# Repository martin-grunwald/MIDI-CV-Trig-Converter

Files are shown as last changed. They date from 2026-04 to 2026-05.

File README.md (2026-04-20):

# MIDI-CV-Trig-Converter

# Zadání
Navrhněte a realizujte převodník rozhraní MIDI na řídicí signály analogových syntezátorů CV/Trig pro modulární systém Eurorack. Převodník bude umožňovat převod zpráv nota zapnuta/vypnuta, zpráv Pitch bend change a zpráv pro změnu kontroleru. Převodník bude disponovat polyfonními výstupy CV, Gate a Trig pro výšku tónu a stlačení klávesy a dalšími výstupy řídicího signálu CV pro kontrolery a bude umožňovat výběr MIDI kontrolru pro každý z těchto výstupů. Převodník bude také obsahovat výstupy Trig pro převod zpráv synchronizace MIDI Clock.

Diagram bez názvu

# Popis
Z MIDI inputu půjdou data do UART portu na STM32 (31250 baud). Zapíše se Note On, Note Off, Výška tónu, Pitch bend a Clock. Note On, Note Off a výšky tónu se uloží pro každý hlas zvlášť.
Polyfonie se může řídit jako round robin nebo last note priority.

Switchem se dají přepínat režimy:
1. 4 hlasy polyfonie a žádný výstup CV z MIDI CC
2. Monofonie a 3 výstupy CV z MIDI CC

Režimů bude nakonec možná víc, ale pak už by se všechno mělo řešit v softwaru. Akorát by se pak použil vícepólový přepínač.

MIDI clock běží na 24ppqn, takže v STM32 bude potřeba vydělit clock rate (na čtvrťovou nebo osminovou notu, podle toho, jak bude potřeba).

Z MCU modelů nejvhodněji vypadá STM32F405RG + 2 externí 12-bitové, dvoukanálové převodníky (MCP4922).

Rozsah CV a V/Oct bude 0 - 10 V, přičemž pitch bend se bude přičítat k výstupu, takže to se bude řídit softwarově.
Jestli bude na výstupu převodníku 0,33V (nebo 0,5V), tak se dá potom použít ještě buffer (OPA1612) a pokud by bylo potřeba, tak ještě jednoduchý RC filtr na vyhlazení průběhu napětí a ochranné diody.

Gate signály by mohly jít z GPIO a do MOSFETu 2N7002. MOSFETY by měly umožnit odebírat růyné namětí v závislosti na tom, jaké napětí je konkrétně potřeba na trigger/gate inputu na jiném modulu (většinou 5V/10V/12V).

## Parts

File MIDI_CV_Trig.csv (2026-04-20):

Reference | Qty | Value | DNP | Exclude from BOM | Exclude from Board | Footprint | Datasheet
C1,C2,C3,C4,C5 | 5 | 100n |  |  |  | Capacitor_SMD:C_0805_2012Metric | ~
C6,C8 | 2 | 10u |  |  |  | Capacitor_SMD:C_0805_2012Metric | ~
C7,C9,C10,C15,C16,C19,C21,C22,C23,C24,C25,C26,C27,C28,C29,C30,C31,C34 | 18 | 0.1u |  |  |  | Capacitor_SMD:C_0805_2012Metric | ~
C11,C12 | 2 | 22u |  |  |  | Capacitor_SMD:C_0805_2012Metric | ~
C13 | 1 | 75p |  |  |  | Capacitor_SMD:C_0805_2012Metric | ~
C14 | 1 | 10u |  |  |  | Capacitor_THT:CP_Radial_D5.0mm_P2.00mm | ~
C17 | 1 | 22u |  |  |  | Capacitor_THT:CP_Radial_D5.0mm_P2.00mm | ~
C18,C20 | 2 | 47ux16V |  |  |  | Capacitor_THT:CP_Radial_D5.0mm_P2.00mm | ~
C32,C33 | 2 | 2.2u |  |  |  | Capacitor_SMD:C_0805_2012Metric | ~
C35 | 1 | 1u |  |  |  | Capacitor_SMD:C_0805_2012Metric | ~
D1 | 1 | 1N4148 |  |  |  | Diode_THT:D_DO-35_SOD27_P7.62mm_Horizontal | https://assets.nexperia.com/documents/data-sheet/1N4148_1N4448.pdf
D2,D3 | 2 | SS34 |  |  |  | Diode_SMD:D_SMA | https://www.vishay.com/docs/88751/ss32.pdf
F1,F2 | 2 | Fuse_Small |  |  |  | Fuse:Fuse_1206_3216Metric | ~
FB1,FB2,FB3,FB4 | 4 | FerriteBead_Small |  |  |  | Inductor_SMD:L_1206_3216Metric | ~
J1 | 1 | Conn_02x05_Odd_Even |  |  |  | Connector_IDC:IDC-Header_2x05_P2.54mm_Vertical | ~
J2,J13 | 2 | Conn_01x03_Pin |  |  |  | Connector_PinHeader_2.54mm:PinHeader_1x03_P2.54mm_Vertical | ~
J3 | 1 | CV1_OUT |  |  |  | Connector_Audio:Jack_3.5mm_QingPu_WQP-PJ398SM_Vertical_CircularHoles | ~
J4 | 1 | CV2_OUT |  |  |  | Connector_Audio:Jack_3.5mm_QingPu_WQP-PJ398SM_Vertical_CircularHoles | ~
J5 | 1 | CV3_OUT |  |  |  | Connector_Audio:Jack_3.5mm_QingPu_WQP-PJ398SM_Vertical_CircularHoles | ~
J6 | 1 | CV4_OUT |  |  |  | Connector_Audio:Jack_3.5mm_QingPu_WQP-PJ398SM_Vertical_CircularHoles | ~
J7 | 1 | CLOCK_OUT |  |  |  | Connector_Audio:Jack_3.5mm_QingPu_WQP-PJ398SM_Vertical_CircularHoles | ~
J8 | 1 | GATE1_OUT |  |  |  | Connector_Audio:Jack_3.5mm_QingPu_WQP-PJ398SM_Vertical_CircularHoles | ~
J9 | 1 | GATE2_OUT |  |  |  | Connector_Audio:Jack_3.5mm_QingPu_WQP-PJ398SM_Vertical_CircularHoles | ~
J10 | 1 | GATE3_OUT |  |  |  | Connector_Audio:Jack_3.5mm_QingPu_WQP-PJ398SM_Vertical_CircularHoles | ~
J11 | 1 | GATE4_OUT |  |  |  | Connector_Audio:Jack_3.5mm_QingPu_WQP-PJ398SM_Vertical_CircularHoles | ~
J12 | 1 | Conn_ARM_JTAG_SWD_10 |  |  |  | Connector_PinHeader_1.27mm:PinHeader_2x05_P1.27mm_Vertical | http://infocenter.arm.com/help/topic/com.arm.doc.ddi0314h/DDI0314H_coresight_components_trm.pdf
L1 | 1 | 10u |  |  |  | Inductor_SMD:L_6.3x6.3_H3 | ~
Q1,Q2,Q3,Q4,Q5 | 5 | 2N7002 |  |  |  | Package_TO_SOT_SMD:SOT-23 | https://www.onsemi.com/pub/Collateral/NDS7002A-D.PDF
R1 | 1 | 49R9 |  |  |  | Resistor_SMD:R_0805_2012Metric | ~
R2,R25,R27,R30,R33,R36 | 6 | 100k |  |  |  | Resistor_SMD:R_0805_2012Metric | ~
R3 | 1 | 13.3k |  |  |  | Resistor_SMD:R_0805_2012Metric | ~
R4 | 1 | 220 |  |  |  | Resistor_SMD:R_0805_2012Metric | ~
R5,R9,R10,R11,R12,R17,R18,R19,R20,R24,R28,R31,R34,R37,R38,R39,R40 | 17 | 10k |  |  |  | Resistor_SMD:R_0805_2012Metric | ~
R6,R13,R14,R21,R22 | 5 | 1k |  |  |  | Resistor_SMD:R_0805_2012Metric | ~
R7,R8,R15,R16,R23,R26,R29,R32,R35 | 9 | 100R |  |  |  | Resistor_SMD:R_0805_2012Metric | ~
TP1 | 1 | TEST_-12V |  |  |  | TestPoint:TestPoint_Pad_1.5x1.5mm | ~
TP2 | 1 | TEST_+12V |  |  |  | TestPoint:TestPoint_Pad_1.5x1.5mm | ~
TP3 | 1 | TEST_5V |  |  |  | TestPoint:TestPoint_Pad_1.5x1.5mm | ~
TP4 | 1 | TEST_3V3 |  |  |  | TestPoint:TestPoint_Pad_1.5x1.5mm | ~
TP5 | 1 | TEST_GND |  |  |  | TestPoint:TestPoint_Pad_2.5x2.5mm | ~
TP6 | 1 | TEST_NRST |  |  |  | TestPoint:TestPoint_Pad_1.5x1.5mm | ~
TP7 | 1 | TEST_DAC1_RAW |  |  |  | TestPoint:TestPoint_Pad_1.5x1.5mm | ~
TP8 | 1 | TEST_DAC2_RAW |  |  |  | TestPoint:TestPoint_Pad_1.5x1.5mm | ~
TP9 | 1 | TEST_DAC3_RAW |  |  |  | TestPoint:TestPoint_Pad_1.5x1.5mm | ~
TP10 | 1 | TEST_DAC4_RAW |  |  |  | TestPoint:TestPoint_Pad_1.5x1.5mm | ~
TP11 | 1 | TEST_DAC1_OUT |  |  |  | TestPoint:TestPoint_Pad_1.5x1.5mm | ~
TP12 | 1 | TEST_DAC2_OUT |  |  |  | TestPoint:TestPoint_Pad_1.5x1.5mm | ~
TP13,TP14 | 2 | TEST_DAC3_OUT |  |  |  | TestPoint:TestPoint_Pad_1.5x1.5mm | ~
U1 | 1 | STM32F405RGTx |  |  |  | Package_QFP:LQFP-64_10x10mm_P0.5mm | https://www.st.com/resource/en/datasheet/stm32f405rg.pdf
U2 | 1 | TPS54302 |  |  |  | Package_TO_SOT_SMD:SOT-23-6 | http://www.ti.com/lit/ds/symlink/tps54302.pdf
U3,U9 | 2 | OPA2277 |  |  |  | Package_SO:SOIC-8_3.9x4.9mm_P1.27mm | https://www.ti.com/lit/ds/symlink/opa2277.pdf
U4 | 1 | LD1117V33 |  |  |  | Package_TO_SOT_SMD:SOT-23_Handsoldering | https://www.st.com/resource/en/datasheet/ld1117.pdf
U5 | 1 | 6N137 |  |  |  | Package_DIP:DIP-8_W7.62mm | https://docs.broadcom.com/docs/AV02-0940EN
U6,U8 | 2 | MCP4822 |  |  |  | Package_SO:SOIC-8_3.9x4.9mm_P1.27mm | http://ww1.microchip.com/downloads/en/DeviceDoc/20002249B.pdf
U7,U10 | 2 | OPA1612AxD |  |  |  | Package_SO:SOIC-8_3.9x4.9mm_P1.27mm | http://www.ti.com/lit/ds/symlink/opa1612.pdf

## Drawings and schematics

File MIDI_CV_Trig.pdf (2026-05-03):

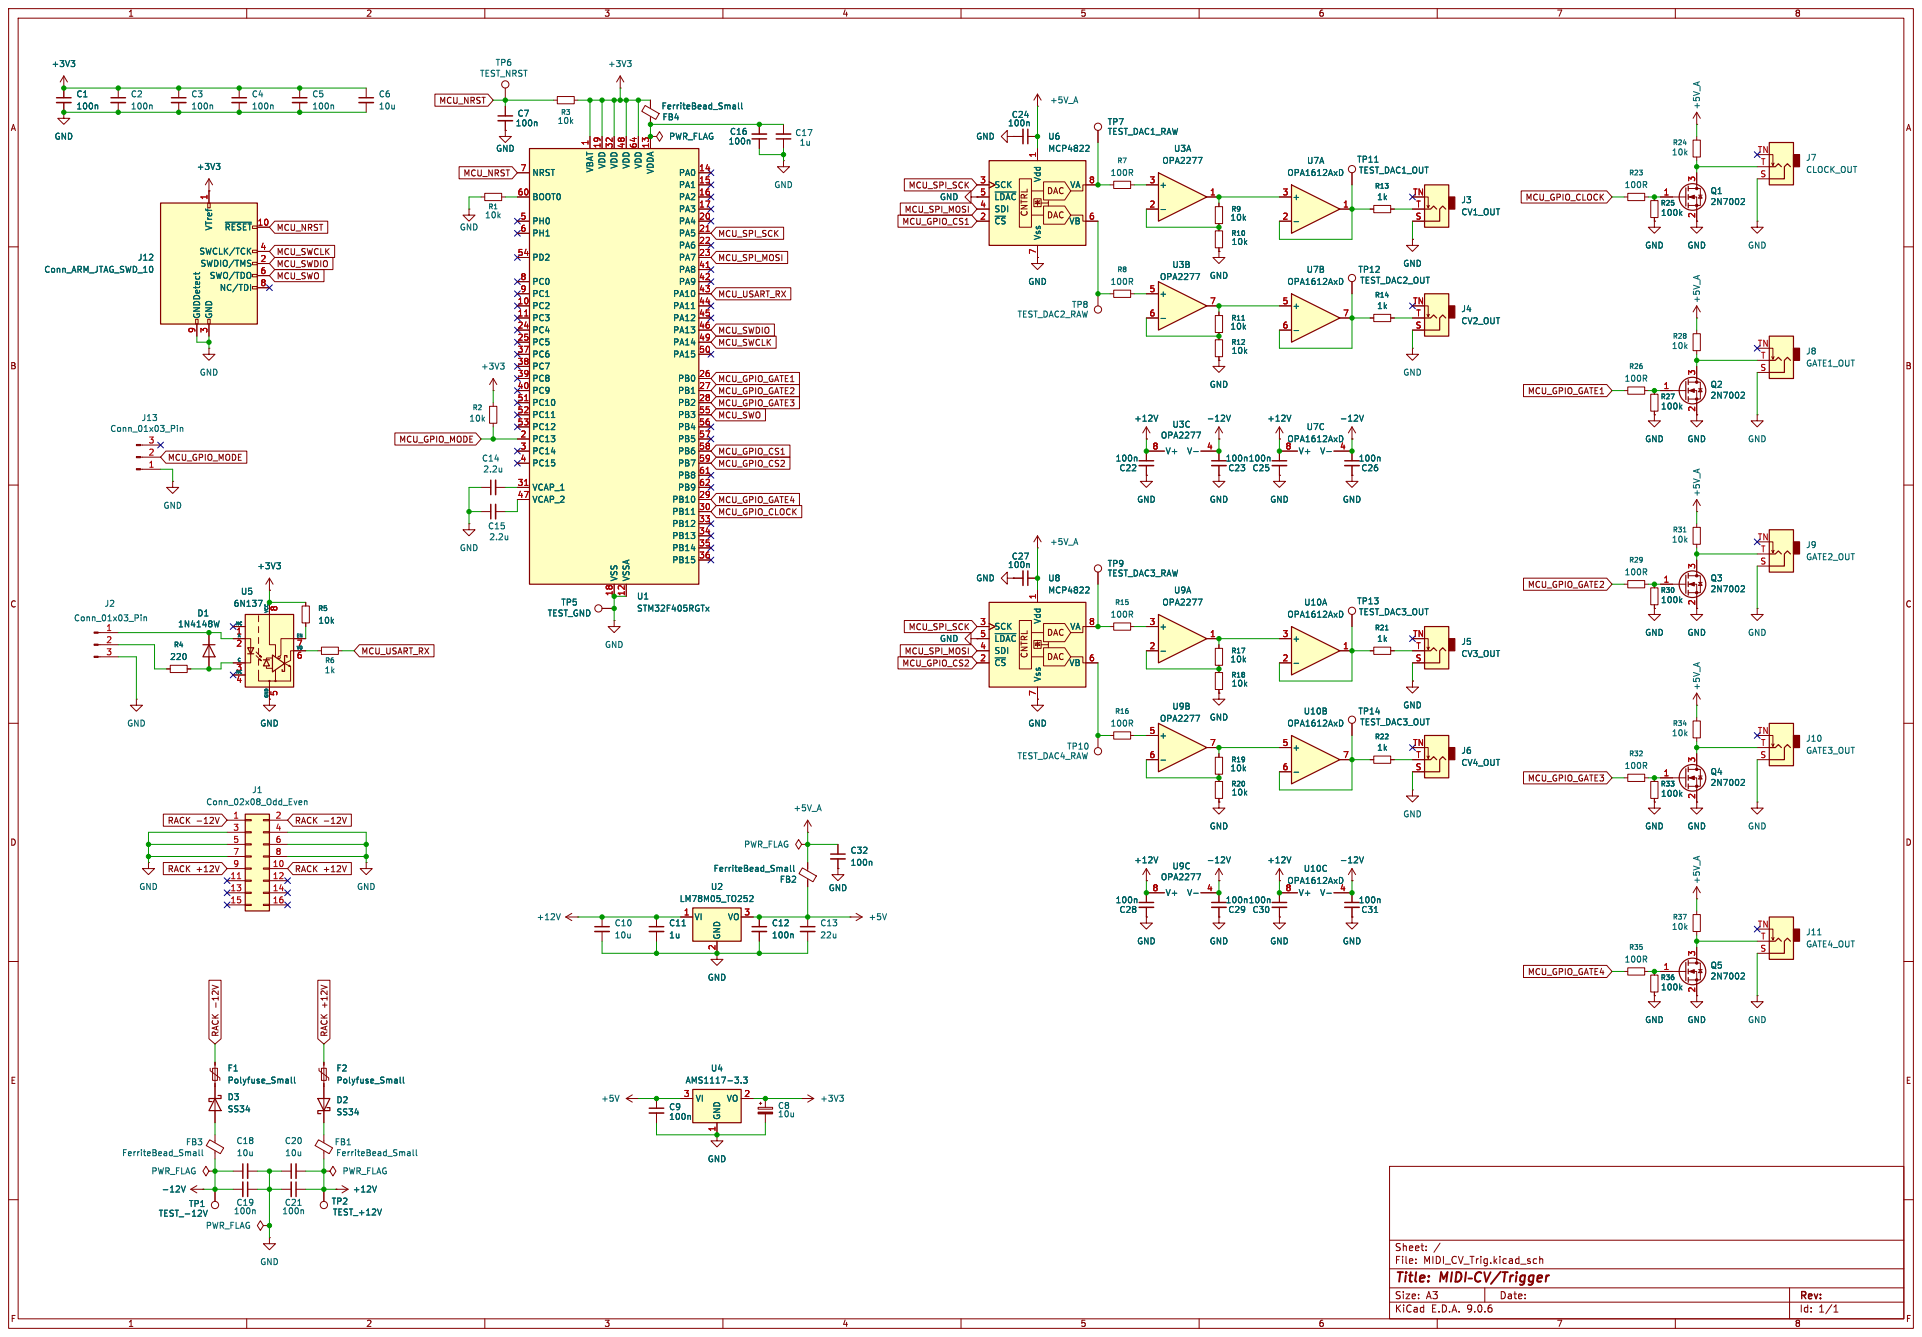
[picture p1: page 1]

3 ~{RESET}10 SWCLK/TCK 4 SWDIO/TMS 2 SWO/TDO 6 NC/TDI 8 C1
100n GND

1 VDD 19 VDD 32 VSS 18 VDD 48 VSSA 12 VDD 64 VDDA 13 PA0 14 PA1 15 PA2 16 PA3 17 PA4 20 PA5 21 PA6 22 PA7 23 PA8 41 PA9 42 PA10 43 PA11 44 PA12 45 PA13 46 PA14 49 PA15 50 PB0 26 PB1 27 PB2 28 PB3 55 PB4 56 PB5 57 PB6 58 PB7 59 PB8 61 PB9 62 PB10 29 PB11 30 PB12 33 PB13 34 PB14 35 PB15 36 +3V3 U5

1 VDD 19 VDD 32 VSS 18 VDD 48 VSSA 12 VDD 64 VDDA 13 PA0 14 PA1 15 PA2 16 PA3 17 PA4 20 PA5 21 PA6 22 PA7 23 PA8 41 PA9 42 PA10 43 PA11 44 PA12 45 PA13 46 PA14 49 PA15 50 PB0 26 PB1 27 PB2 28 PB3 55 PB4 56 PB5 57 PB6 58 PB7 59 PB8 61 PB9 62 PB10 29 PB11 30 PB12 33 PB13 34 PB14 35 PB15 36 U1STM32F405RGTx R14 1k TP12 TEST_DAC2_OUT C14
J3CV1_OUT GND

1 Vss 7 VA 8 VB 6 GND GND

3 ~{RESET}10 SWCLK/TCK 4 SWDIO/TMS 2 SWO/TDO 6 NC/TDI 8

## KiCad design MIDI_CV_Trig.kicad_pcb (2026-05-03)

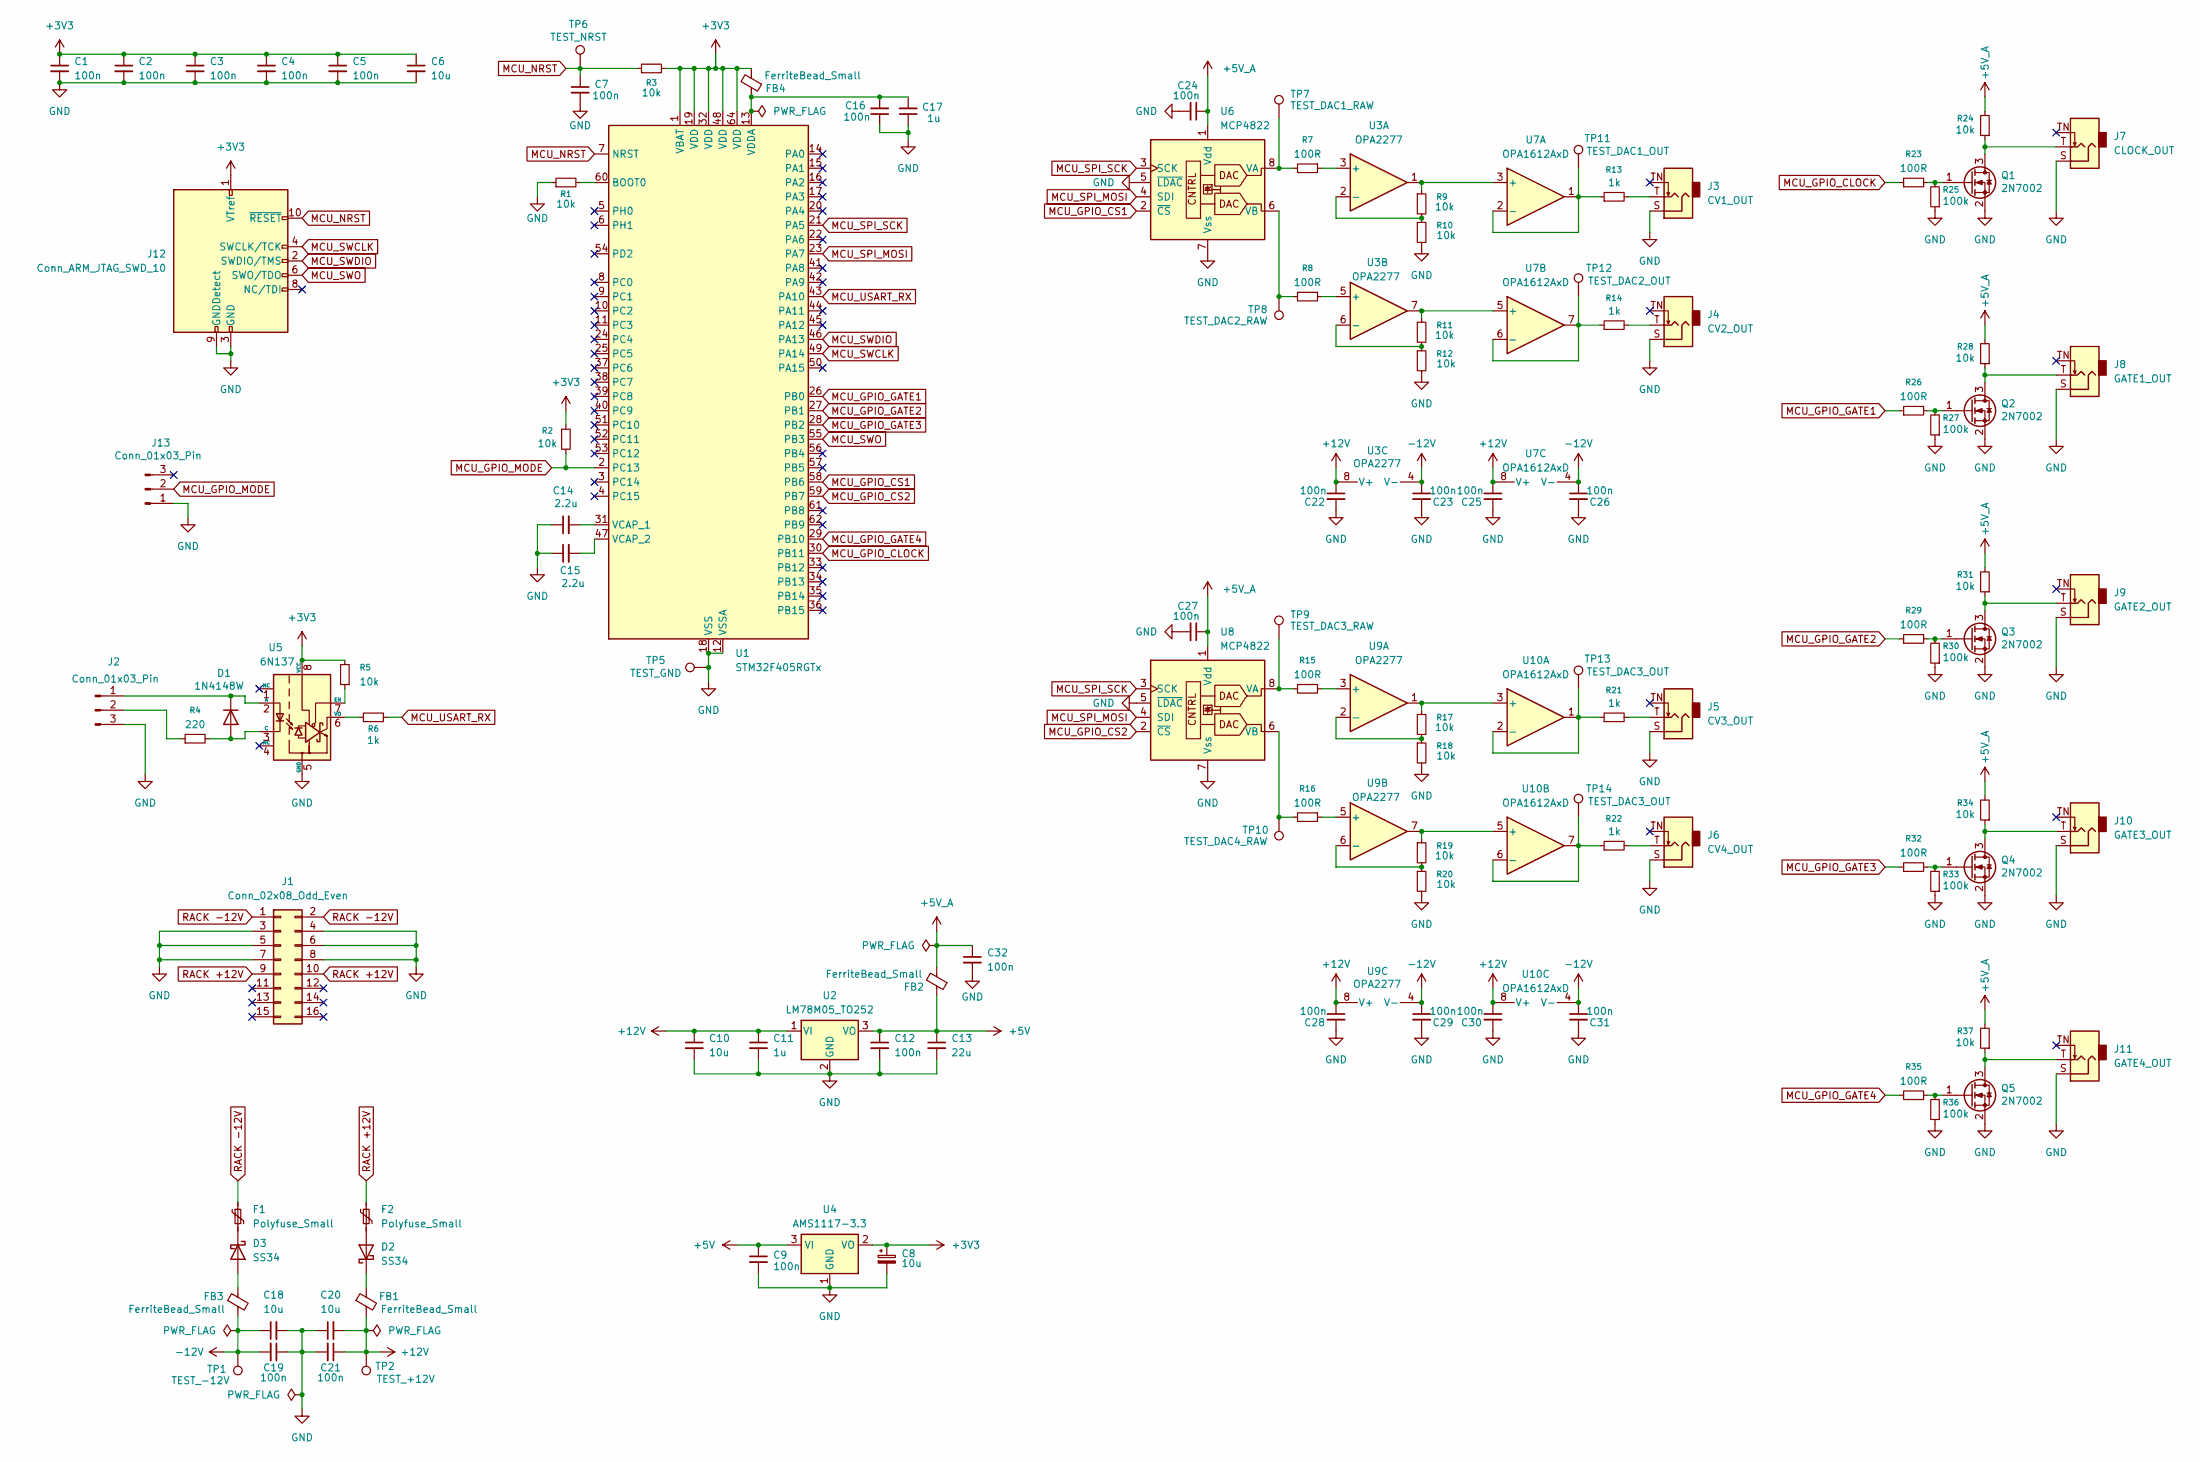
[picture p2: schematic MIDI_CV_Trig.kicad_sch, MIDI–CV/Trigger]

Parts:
C1, C2, C3, C4, C5, C7, C9, C12, C16, C22, C23, C24, C25, C26, C27, C28, C29, C30, C31, C32: 100n; C_0603_1608Metric; JLCPCB C14663
C6, C10, C18, C20: 10u; C_1206_3216Metric; JLCPCB C13585
C8: 10u; CP_EIA-3216-18_Kemet-A; JLCPCB C7171
C11, C17: 1u; C_0603_1608Metric; JLCPCB C15849
C13: 22u; C_1206_3216Metric; JLCPCB C12891
C14, C15: 2.2u; C_0603_1608Metric; JLCPCB C23630
C19, C21: 100n; C_1206_3216Metric; JLCPCB C14663
D1: 1N4148W; D_SOD-123; JLCPCB C2128
D2, D3: SS34; D_SMA; JLCPCB C8678
F1, F2: Polyfuse_Small; Fuse_1206_3216Metric; JLCPCB C70076
FB1, FB2, FB3, FB4: FerriteBead_Small; L_1206_3216Metric; JLCPCB C19330
J1: Conn_02x08_Odd_Even; IDC-Header_2x08_P2.54mm_Vertical
J2, J13: Conn_01x03_Pin; PinHeader_1x03_P2.54mm_Vertical
J3: CV1_OUT; Jack_3.5mm_QingPu_WQP-PJ398SM_Vertical_CircularHoles
J4: CV2_OUT; Jack_3.5mm_QingPu_WQP-PJ398SM_Vertical_CircularHoles
J5: CV3_OUT; Jack_3.5mm_QingPu_WQP-PJ398SM_Vertical_CircularHoles
J6: CV4_OUT; Jack_3.5mm_QingPu_WQP-PJ398SM_Vertical_CircularHoles
J7: CLOCK_OUT; Jack_3.5mm_QingPu_WQP-PJ398SM_Vertical_CircularHoles
J8: GATE1_OUT; Jack_3.5mm_QingPu_WQP-PJ398SM_Vertical_CircularHoles
J9: GATE2_OUT; Jack_3.5mm_QingPu_WQP-PJ398SM_Vertical_CircularHoles
J10: GATE3_OUT; Jack_3.5mm_QingPu_WQP-PJ398SM_Vertical_CircularHoles
J11: GATE4_OUT; Jack_3.5mm_QingPu_WQP-PJ398SM_Vertical_CircularHoles
J12: Conn_ARM_JTAG_SWD_10; PinHeader_2x05_P2.54mm_Vertical
Q1, Q2, Q3, Q4, Q5: 2N7002; SOT-23; JLCPCB C8545
R1, R2, R3, R5, R9, R10, R11, R12, R17, R18, R19, R20, R24, R28, R31, R34, R37: 10k; R_0603_1608Metric; JLCPCB C25804
R4: 220; R_0603_1608Metric; JLCPCB C23162
R6, R13, R14, R21, R22: 1k; R_0603_1608Metric; JLCPCB C21190
R7, R8, R15, R16, R23, R26, R29, R32, R35: 100R; R_0603_1608Metric; JLCPCB C22775
R25, R27, R30, R33, R36: 100k; R_0603_1608Metric; JLCPCB C25803
TP1: TEST_-12V; TestPoint_Pad_1.5x1.5mm
TP2: TEST_+12V; TestPoint_Pad_1.5x1.5mm
TP5: TEST_GND; TestPoint_Pad_2.5x2.5mm
TP6: TEST_NRST; TestPoint_Pad_1.5x1.5mm
TP7: TEST_DAC1_RAW; TestPoint_Pad_1.5x1.5mm
TP8: TEST_DAC2_RAW; TestPoint_Pad_1.5x1.5mm
TP9: TEST_DAC3_RAW; TestPoint_Pad_1.5x1.5mm
TP10: TEST_DAC4_RAW; TestPoint_Pad_1.5x1.5mm
TP11: TEST_DAC1_OUT; TestPoint_Pad_1.5x1.5mm
TP12: TEST_DAC2_OUT; TestPoint_Pad_1.5x1.5mm
TP13, TP14: TEST_DAC3_OUT; TestPoint_Pad_1.5x1.5mm
U1: STM32F405RGTx; LQFP-64_10x10mm_P0.5mm; JLCPCB C15742
U2: LM78M05_TO252; TO-252-2; JLCPCB C544492
U3, U9: OPA2277; SOIC-8_3.9x4.9mm_P1.27mm; JLCPCB C24460
U4: AMS1117-3.3; SOT-223-3_TabPin2; JLCPCB C6186
U5: 6N137; SMDIP-8_W7.62mm; JLCPCB C15825
U6, U8: MCP4822; SOIC-8_3.9x4.9mm_P1.27mm; JLCPCB C16040
U7, U10: OPA1612AxD; SOIC-8_3.9x4.9mm_P1.27mm; JLCPCB C94590

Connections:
+3V3: C1.1, C2.1, C3.1, C4.1, C5.1, C6.1, C8.1, FB4.2, J12.1 (VTref), R2.1, R3.2, R5.2, U1.1 (VBAT), U1.19 (VDD), U1.32 (VDD), U1.48 (VDD), U1.64 (VDD), U4.2 (VO), U5.8 (VCC)
+5V: C9.1, C12.1, C13.1, FB2.1, U2.3 (VO), U4.3 (VI)
+5V_A: C24.1, C27.1, C32.1, FB2.2, R24.2, R28.2, R31.2, R34.2, R37.2, U6.1 (Vdd), U8.1 (Vdd)
+12V: C10.1, C11.1, C20.2, C21.1, C22.1, C25.1, C28.1, C30.1, FB1.2, TP2.1, U2.1 (VI), U3.8 (V+), U7.8 (V+), U9.8 (V+), U10.8 (V+)
-12V: C18.1, C19.2, C23.1, C26.1, C29.1, C31.1, FB3.2, TP1.1, U3.4 (V-), U7.4 (V-), U9.4 (V-), U10.4 (V-)
GND: C1.2, C2.2, C3.2, C4.2, C5.2, C6.2, C7.2, C8.2, C9.2, C10.2, C11.2, C12.2, C13.2, C14.1, C15.1, C16.1, C17.1, C18.2, C19.1, C20.1, C21.2, C22.2, C23.2, C24.2, C25.2, C26.2, C27.2, C28.2, C29.2, C30.2, C31.2, C32.2, J1.3, J1.4, J1.5, J1.6, J1.7, J1.8, J2.3, J3.S, J4.S, J5.S, J6.S, J7.S, J8.S, J9.S, J10.S, J11.S, J12.3 (GND), J12.5 (GND), J12.9 (GNDDetect), J13.1, Q1.2 (S), Q2.2 (S), Q3.2 (S), Q4.2 (S), Q5.2 (S), R1.1, R10.2, R12.2, R18.2, R20.2, R25.1, R27.1, R30.1, R33.1, R36.1, TP5.1, U1.12 (VSSA), U1.18 (VSS), U1.63 (VSS), U2.2 (GND), U4.1 (GND), U5.5 (GND), U6.5 (~LDAC), U6.7 (Vss), U8.5 (~LDAC), U8.7 (Vss)
MCU_GPIO_CLOCK: R23.1, U1.30 (PB11)
MCU_GPIO_CS1: U1.58 (PB6), U6.2 (~CS)
MCU_GPIO_CS2: U1.59 (PB7), U8.2 (~CS)
MCU_GPIO_GATE1: R26.1, U1.26 (PB0)
MCU_GPIO_GATE2: R29.1, U1.27 (PB1)
MCU_GPIO_GATE3: R32.1, U1.28 (PB2)
MCU_GPIO_GATE4: R35.1, U1.29 (PB10)
MCU_GPIO_MODE: J13.2, R2.2, U1.2 (PC13)
MCU_NRST: C7.1, J12.10 (~RESET), R3.1, TP6.1, U1.7 (NRST)
MCU_SPI_MOSI: U1.23 (PA7), U6.4 (SDI), U8.4 (SDI)
MCU_SPI_SCK: U1.21 (PA5), U6.3 (SCK), U8.3 (SCK)
MCU_SWCLK: J12.4 (SWCLK/TCK), U1.49 (PA14)
MCU_SWDIO: J12.2 (SWDIO/TMS), U1.46 (PA13)
MCU_SWO: J12.6 (SWO/TDO), U1.55 (PB3)
MCU_USART_RX: R6.2, U1.43 (PA10)
unnamed: D1.2 (A), R4.2, U5.3 (C)
unnamed: D1.1 (K), J2.1, U5.2 (A)
unnamed: D2.2 (A), F2.2
unnamed: D2.1 (K), FB1.1
unnamed: D3.2 (A), FB3.1
unnamed: D3.1 (K), F1.2
unnamed: J2.2, R4.1
unnamed: J3.T, R13.2
unnamed: J4.T, R14.2
unnamed: J5.T, R21.2
unnamed: J6.T, R22.2
unnamed: J7.T, Q1.3 (D), R24.1
unnamed: Q1.1 (G), R23.2, R25.2
unnamed: J8.T, Q2.3 (D), R28.1
unnamed: Q2.1 (G), R26.2, R27.2
unnamed: J9.T, Q3.3 (D), R31.1
unnamed: Q3.1 (G), R29.2, R30.2
unnamed: J10.T, Q4.3 (D), R34.1
unnamed: Q4.1 (G), R32.2, R33.2
unnamed: J11.T, Q5.3 (D), R37.1
unnamed: Q5.1 (G), R35.2, R36.2
unnamed: R1.2, U1.60 (BOOT0)
unnamed: C14.2, U1.31 (VCAP_1)
unnamed: C15.2, U1.47 (VCAP_2)
unnamed: C16.2, C17.2, FB4.1, U1.13 (VDDA)
unnamed: R7.1, U3.3 (+)
unnamed: R9.2, R10.1, U3.2 (-)
unnamed: R8.1, U3.5 (+)
unnamed: R11.2, R12.1, U3.6 (-)
unnamed: R5.1, U5.7 (EN)
unnamed: R6.1, U5.6 (VO)
unnamed: R7.2, TP7.1, U6.8 (VA)
unnamed: R8.2, TP8.1, U6.6 (VB)
unnamed: R9.1, U3.1, U7.3 (+)
unnamed: R13.1, TP11.1, U7.1, U7.2 (-)
unnamed: R11.1, U3.7, U7.5 (+)
unnamed: R14.1, TP12.1, U7.6 (-), U7.7
unnamed: R15.2, TP9.1, U8.8 (VA)
unnamed: R16.2, TP10.1, U8.6 (VB)
unnamed: R15.1, U9.3 (+)
unnamed: R17.2, R18.1, U9.2 (-)
unnamed: R16.1, U9.5 (+)
unnamed: R19.2, R20.1, U9.6 (-)
unnamed: R17.1, U9.1, U10.3 (+)
unnamed: R21.1, TP13.1, U10.1, U10.2 (-)
unnamed: R19.1, U9.7, U10.5 (+)
unnamed: R22.1, TP14.1, U10.6 (-), U10.7
RACK +12V: F2.1, J1.9, J1.10
RACK -12V: F1.1, J1.1, J1.2

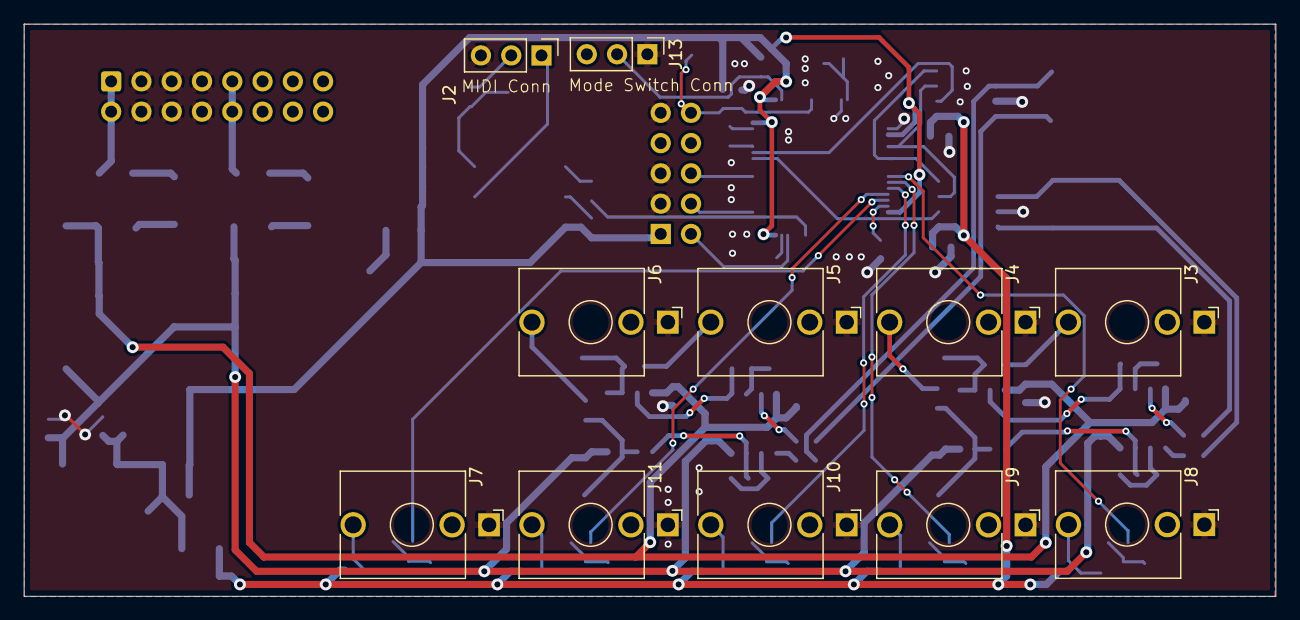
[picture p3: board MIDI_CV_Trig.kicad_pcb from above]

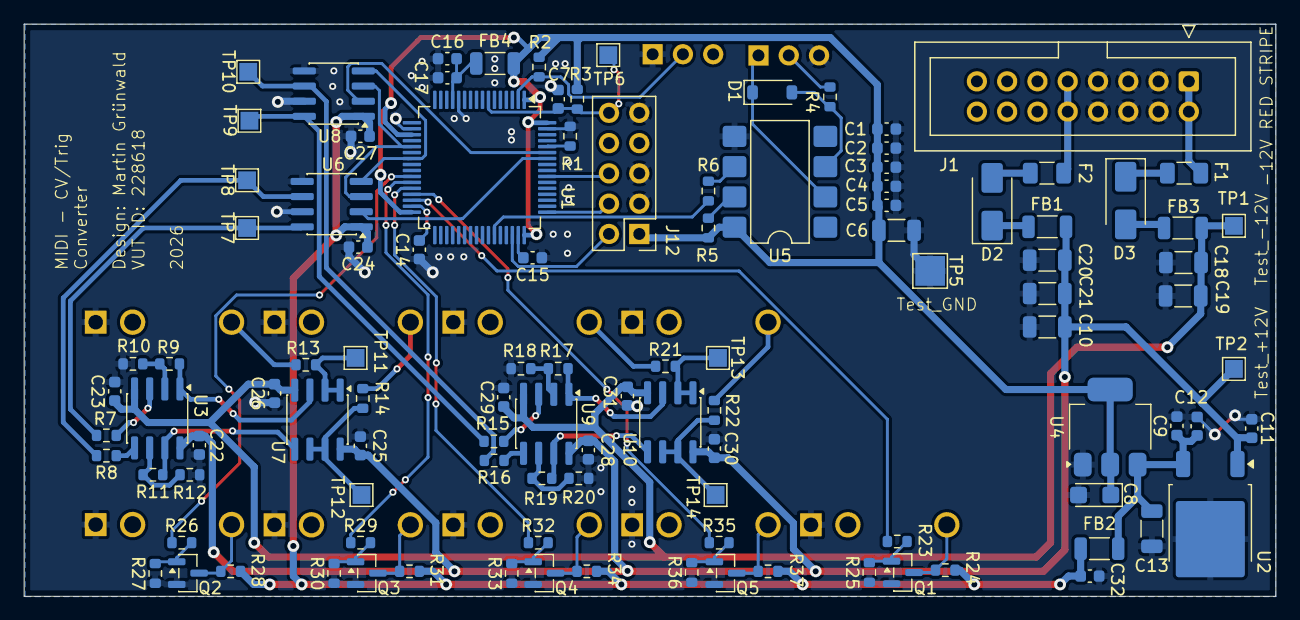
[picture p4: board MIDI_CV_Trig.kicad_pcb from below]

Board: 2 copper layers, 105.0 x 48.0 mm, 118 parts (107 on the bottom side), 70 nets.
